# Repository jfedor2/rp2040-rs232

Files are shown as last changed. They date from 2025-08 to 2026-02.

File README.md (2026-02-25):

# RS-232 adapter with an RP2040 chip

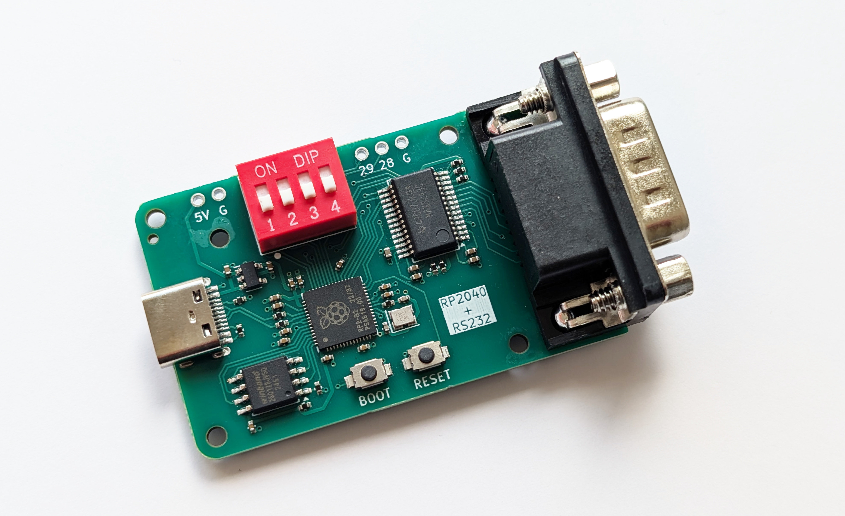
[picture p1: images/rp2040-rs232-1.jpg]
rp2040-rs232 board


This repository contains design files and firmware for a board that can be used as an RS-232 (serial) to USB adapter. It has an RP2040 chip for the application logic and a MAX3243 chip for the serial interface.

The provided firmware supports classic serial mice, two types of 3D mice (Magellan/SpaceMouse and Spaceball 2003), the SpaceOrb 360 game controller, and can also act as a generic serial-to-USB adapter.

## How to make the device

I used [JLCPCB](https://jlcpcb.com/) to make the board. The files in the [fabrication](fabrication) folder can be used with JLCPCB directly. If you want to use some other service, check the file formats that they expect. When ordering from JLCPCB, upload the Gerber zip, leave all the settings at default (you can choose the PCB color), then enable "PCB Assembly" and upload the BOM and CPL files in the next step.

Models for a 3D-printable case can be found in the [3d-printed-case](3d-printed-case) folder. The cases uses four M2x12 countersunk screws and (optionally) one M2x4 screw to secure the board to the case.

## Firmware

The provided firmware combines five separate projects and lets you choose between them using the DIP switches on the board. This way you can have a multi-purpose adapter without having to re-flash the firmware every time.

To flash the board with the firmware, press and hold the BOOT button, then while holding it press and release the RESET button. A drive named "RPI-RP2" should appear on your computer. Copy the [multi-firmware.uf2](https://github.com/jfedor2/rp2040-rs232/releases/latest/download/multi-firmware.uf2) file to that drive. After it's done flashing the drive will disappear and that's it.

project | description | DIP switch setting
------- | ----------- | ------------------
[HID Remapper](https://github.com/jfedor2/hid-remapper) | Adapts classic serial mice to USB | off-off-off-ON
[spaceball-2003](https://github.com/jfedor2/spaceball-2003) | Lets you use a Spaceball 2003 with modern software | off-off-ON-off
[magellan-spacemouse](https://github.com/jfedor2/magellan-spacemouse) | Lets you use a serial Magellan/SpaceMouse with modern software | off-off-ON-ON
[pico-uart-bridge](https://github.com/Noltari/pico-uart-bridge) | Generic USB-to-serial bridge | off-ON-off-off
[spaceorb360](https://github.com/jfedor2/spaceorb360)<br>(spacemouse) | Lets you use a SpaceOrb 360 with modern CAD software | off-ON-off-ON
[spaceorb360](https://github.com/jfedor2/spaceorb360)<br>(joystick) | Lets you use a SpaceOrb 360 with games like Descent | off-ON-ON-off

You can of course use any other firmware meant for the RP2040 chip if you want.

## How to compile

The easiest way to compile the firmware is to let GitHub do it for you. This repository has GitHub Actions that build the firmware, so you can just fork, enable Actions, make your changes, wait for the job to complete, and look for the binary in the artifacts produced.

To compile the firmware on your machine, use the following steps (details may vary depending on your Linux distribution):

```
sudo apt install gcc-arm-none-eabi libnewlib-arm-none-eabi libstdc++-arm-none-eabi-newlib
git clone https://github.com/jfedor2/rp2040-rs232.git
cd rp2040-rs232/multi-firmware
git submodule update --init
for submodule in hid-remapper magellan-spacemouse spaceball-2003 pico-uart-bridge spaceorb360
do
cd $submodule; git submodule update --init; cd ..
done
mkdir build
cd build
cmake ..
make
```

## License

The software in this repository is licensed under the [MIT License](LICENSE), unless stated otherwise. 

The hardware designs in this repository are licensed under the Creative Commons Attribution 4.0 International license ([CC BY 4.0](https://creativecommons.org/licenses/by/4.0/)), unless stated otherwise.

## Acknowledgments

PCB design uses [Type-C.pretty](https://github.com/ai03-2725/Type-C.pretty) library by [ai03-2725](https://github.com/ai03-2725).

Multi-firmware includes [pico-uart-bridge](https://github.com/Noltari/pico-uart-bridge) by [Noltari](https://github.com/Noltari).

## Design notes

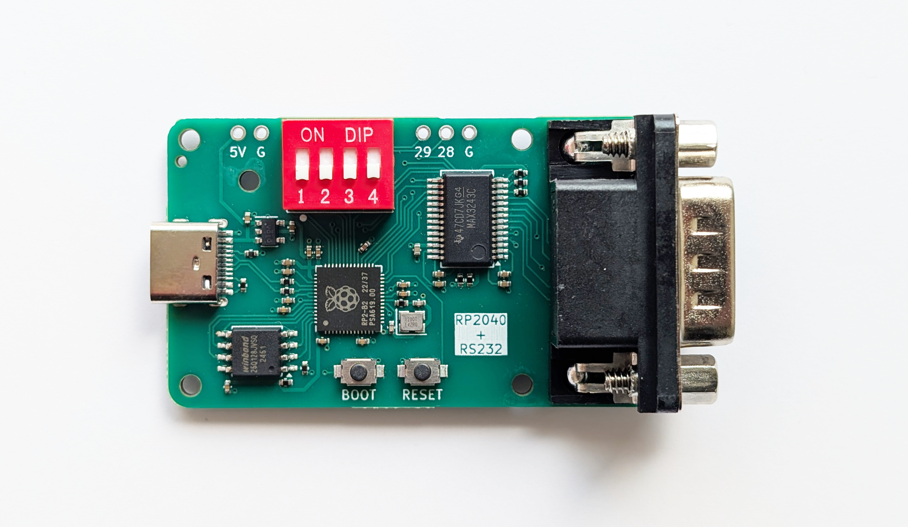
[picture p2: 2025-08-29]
images/rp2040-rs232-2.jpg

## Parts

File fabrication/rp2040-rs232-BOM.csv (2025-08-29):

Value | Reference | Footprint | LCSC
100n | C1,C2,C3,C4,C5,C6,C7,C8,C9,C16 | Capacitor_SMD:C_0402_1005Metric | C1525
1u | C10,C11,C12,C13,C17,C18,C19,C20 | Capacitor_SMD:C_0402_1005Metric | C52923
15p | C14,C15 | Capacitor_SMD:C_0402_1005Metric | C1548
10u | C21 | Capacitor_SMD:C_0402_1005Metric | C15525
DE9_Pins | J1 | DE-9:C19077344 | C19077344
27 | R1,R2 | Resistor_SMD:R_0402_1005Metric | C138021
10k | R3,R4,R6,R10,R11,R12 | Resistor_SMD:R_0402_1005Metric | C25744
1k | R5,R7 | Resistor_SMD:R_0402_1005Metric | C11702
5.1k | R8,R9 | Resistor_SMD:R_0402_1005Metric | C25905
SW_DIP_x04 | SW1 | DIP:C92645 | C92645
SW_Push | SW19,SW20 | SW:C720477 | C720477
RP2040 | U1 | RP2040:RP2040-QFN-56 | C2040
TLV73333PDBV | U2 | SOT-23-5:SOT-23-5 | C134139
W25Q128JVS | U3 | SOIC:SOIC-8_5.23x5.23mm_P1.27mm | C97521
MAX3243 | U5 | MAX3243:SSOP-28_5.3x10.2mm_P0.65mm | C414614
HRO-TYPE-C-31-M-12 | USB1 | Type-C:HRO-TYPE-C-31-M-12-Assembly | C165948
Crystal_GND24 | Y1 | Crystal:Crystal_SMD_2520-4Pin_2.5x2.0mm | C90603

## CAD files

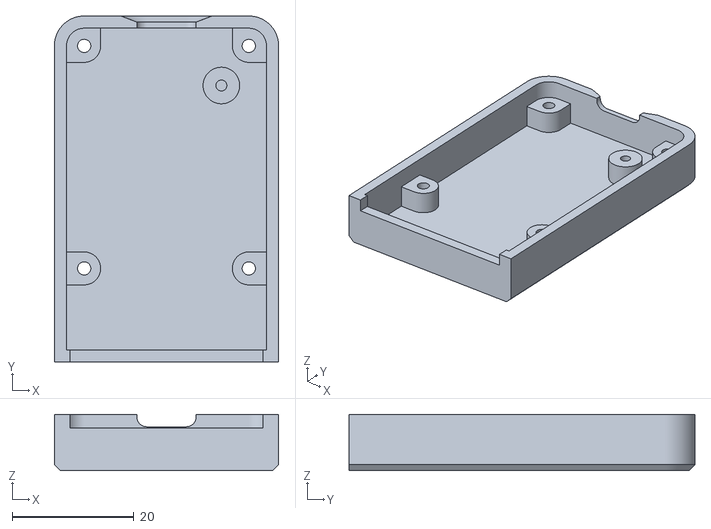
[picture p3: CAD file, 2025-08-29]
3d-printed-case/rp2040-rs232-Bottom.stl
36.8 x 56.8 x 9.23

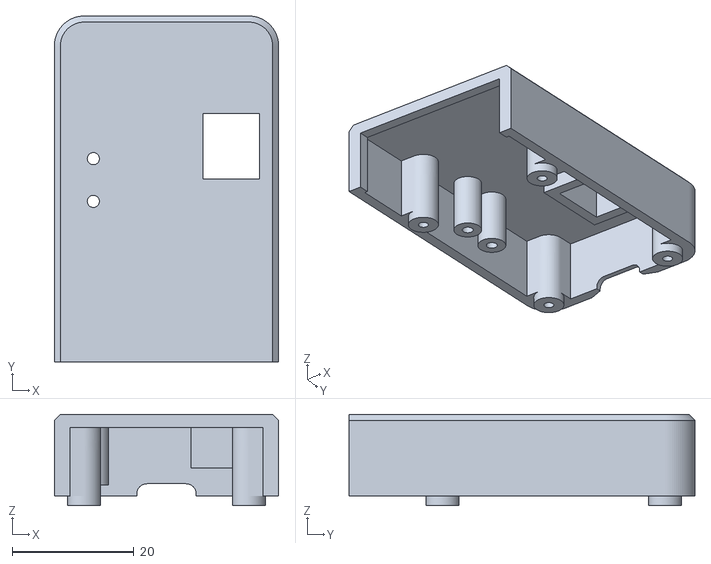
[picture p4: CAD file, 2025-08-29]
3d-printed-case/rp2040-rs232-Top.stl
36.8 x 56.8 x 15.0

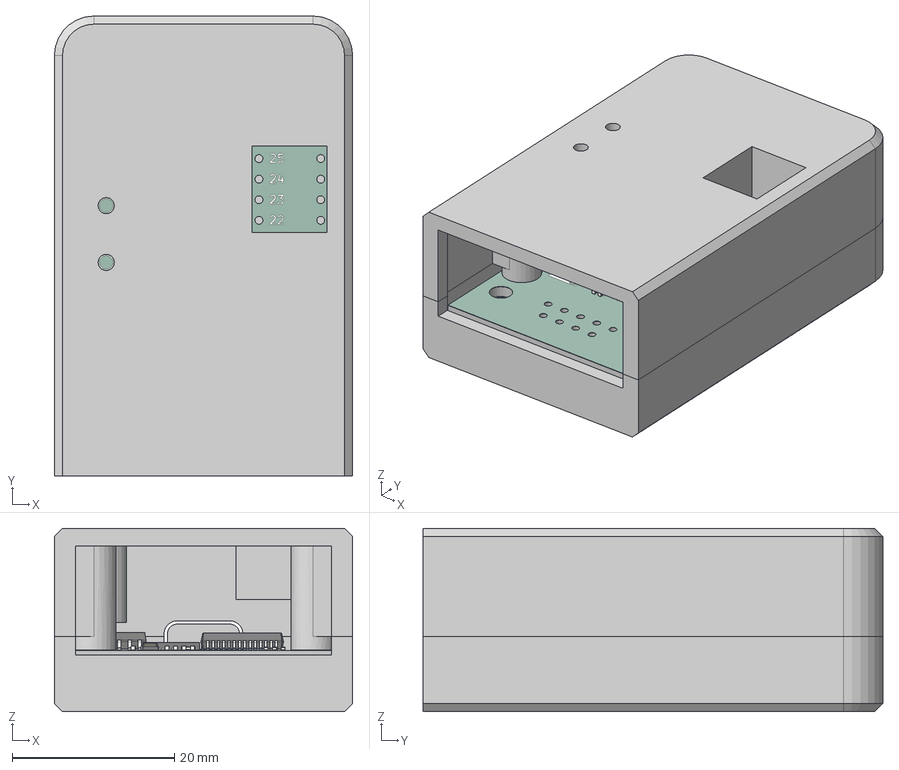
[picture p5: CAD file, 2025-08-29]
3d-printed-case/rp2040-rs232-case.step
36.8 x 56.8 x 22.6 mm
R_0402_1005Metric x 12
HRO-TYPE-C-31-M-12
C_0402_1005Metric x 21
SSOP-28_5.3x10.2mm_P0.65mm
Crystal_SMD_2520-4Pin_2.5x2.0mm
SOIC-8_5.3x5.3mm_P1.27mm
QFN-56-1EP_7x7mm_P0.4mm_EP5.6x5.6mm
SOT-23-5
rp2040-rs232_silkscreen
rp2040-rs232_soldermask
rp2040-rs232_PCB

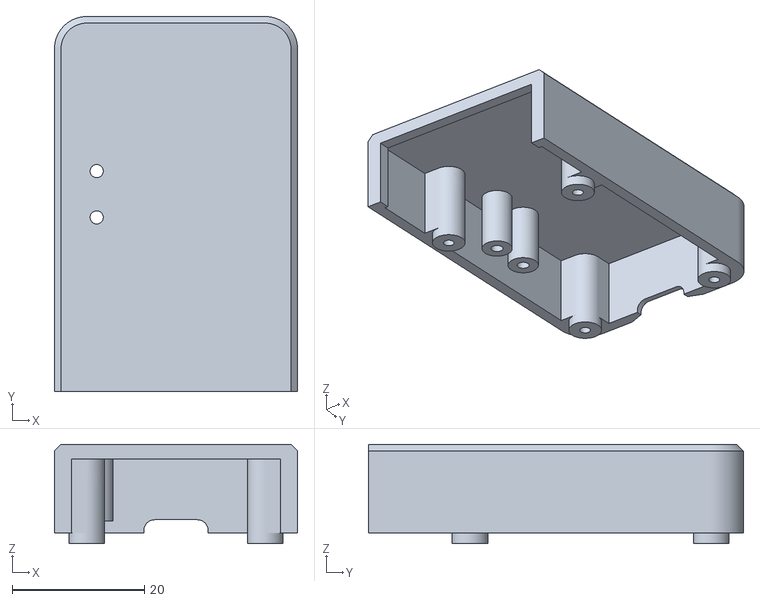
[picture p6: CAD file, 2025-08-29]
3d-printed-case/rp2040-rs232-Top-no-dip-switch-window.stl
36.8 x 56.8 x 15.0

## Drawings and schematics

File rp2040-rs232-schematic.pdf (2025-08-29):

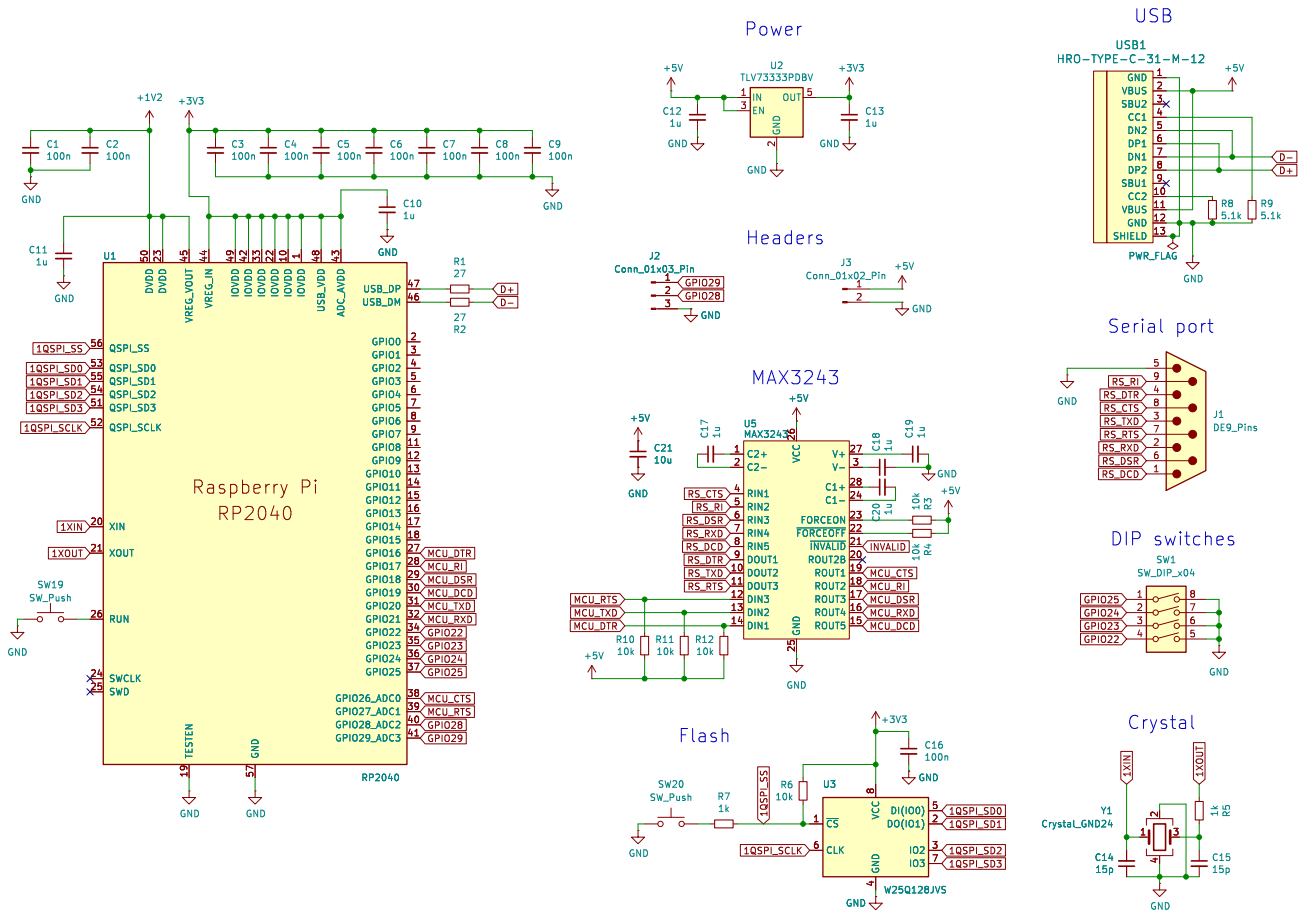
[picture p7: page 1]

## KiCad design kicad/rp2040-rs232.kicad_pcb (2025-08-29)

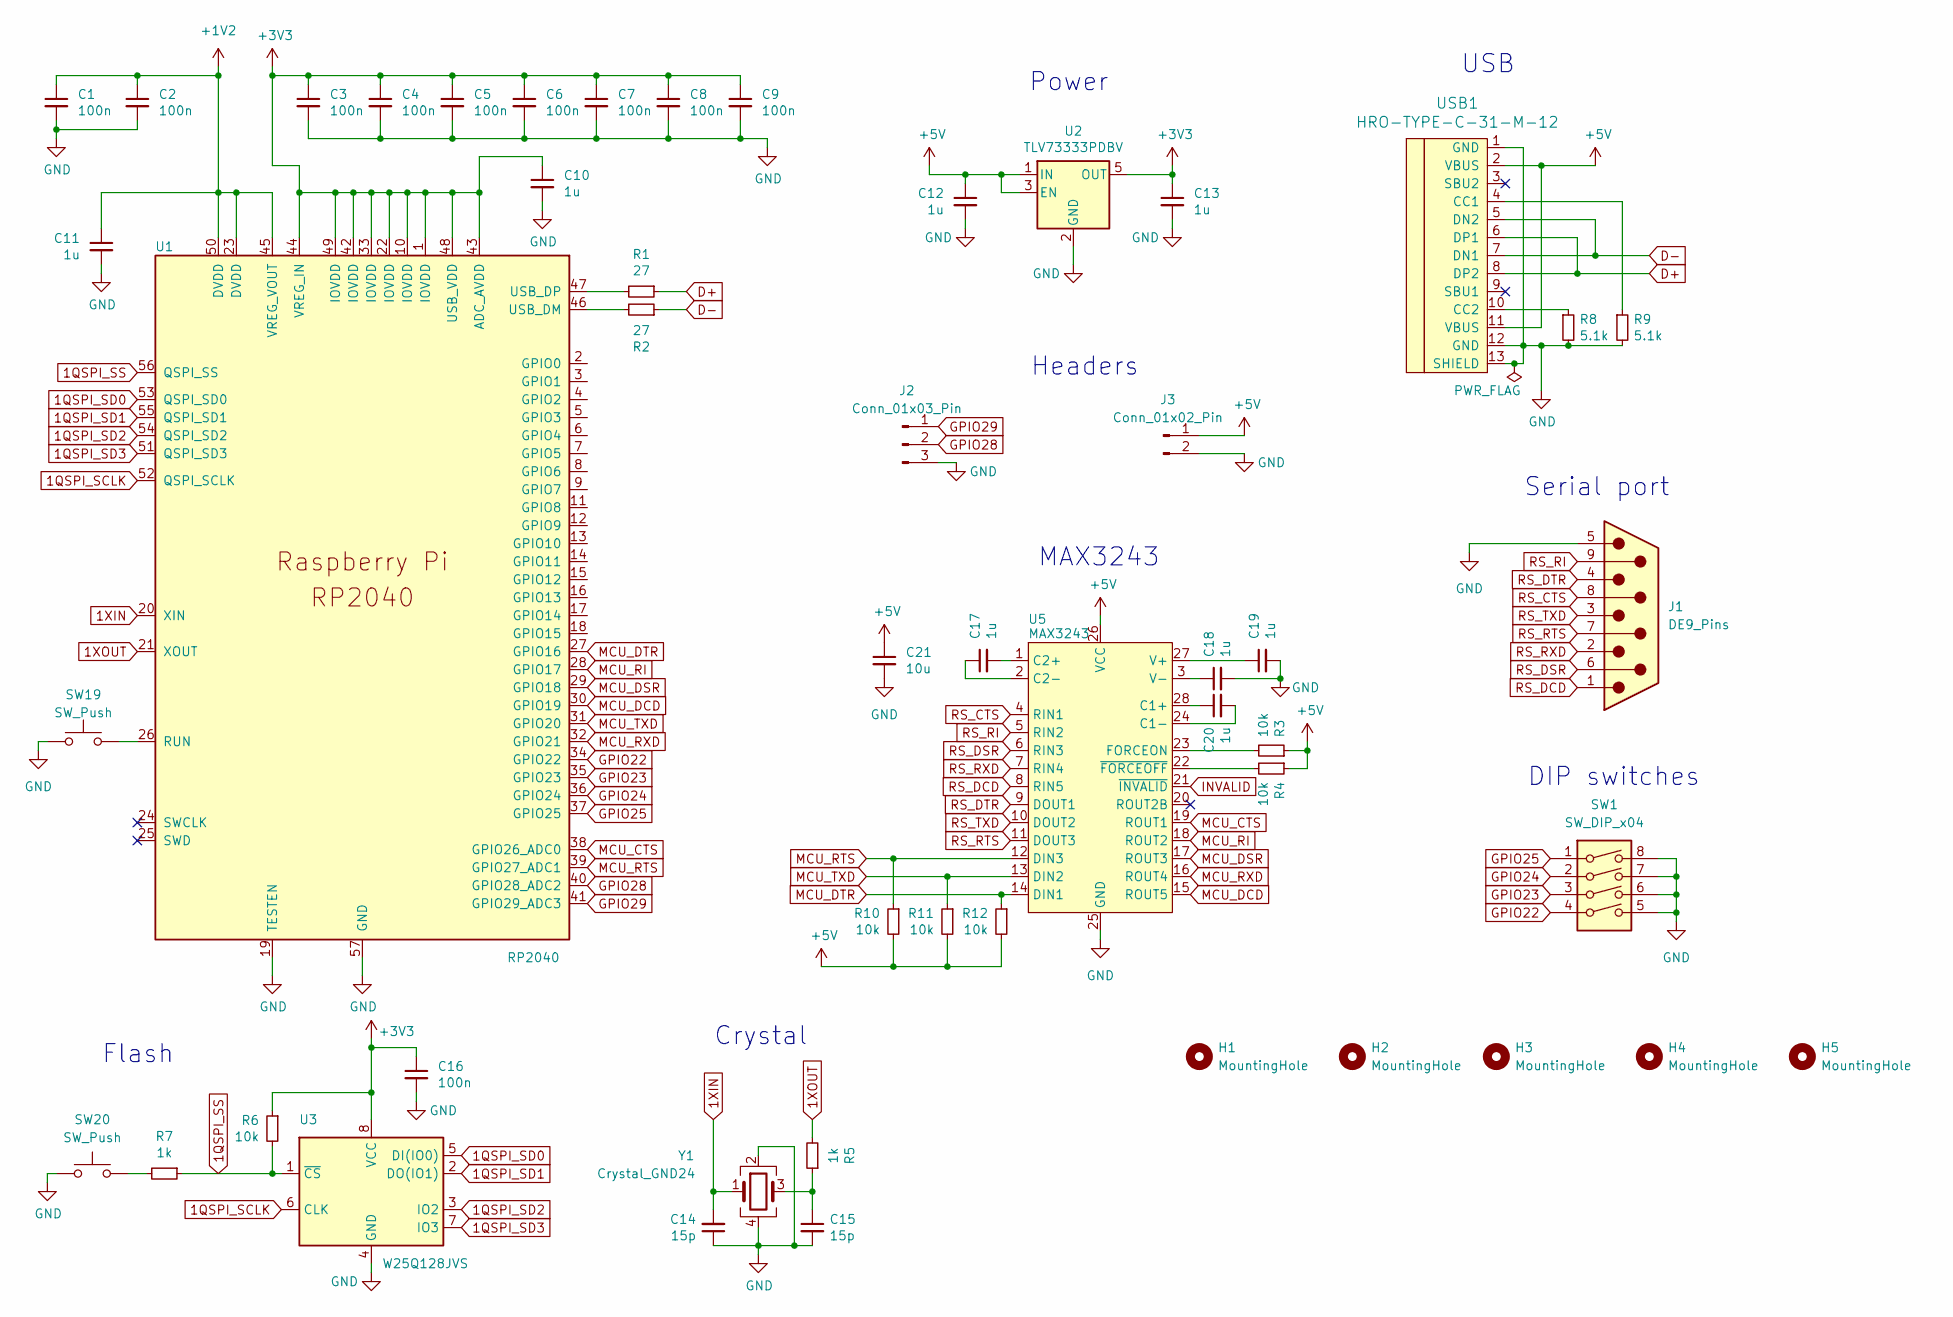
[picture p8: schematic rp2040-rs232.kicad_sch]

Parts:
C1, C2, C3, C4, C5, C6, C7, C8, C9, C16: 100n; C_0402_1005Metric; LCSC C1525
C10, C11, C12, C13, C17, C18, C19, C20: 1u; C_0402_1005Metric; LCSC C52923
C14, C15: 15p; C_0402_1005Metric; LCSC C1548
C21: 10u; C_0402_1005Metric; LCSC C15525
H1, H2, H3, H4, H5: MountingHole; MountingHole_2.2mm_M2
J1: DE9_Pins; C19077344; LCSC C19077344
J2: Conn_01x03_Pin; PinHeader_1x03_P2.54mm_Vertical
J3: Conn_01x02_Pin; PinHeader_1x02_P2.54mm_Vertical
R1, R2: 27; R_0402_1005Metric; LCSC C138021
R3, R4, R6, R10, R11, R12: 10k; R_0402_1005Metric; LCSC C25744
R5, R7: 1k; R_0402_1005Metric; LCSC C11702
R8, R9: 5.1k; R_0402_1005Metric; LCSC C25905
SW1: SW_DIP_x04; C92645; LCSC C92645
SW19, SW20: SW_Push; C720477; LCSC C720477
U1: RP2040; RP2040-QFN-56; LCSC C2040
U2: TLV73333PDBV; SOT-23-5; LCSC C134139
U3: W25Q128JVS; SOIC-8_5.23x5.23mm_P1.27mm; LCSC C97521
U5: MAX3243; SSOP-28_5.3x10.2mm_P0.65mm; LCSC C414614
USB1: HRO-TYPE-C-31-M-12; HRO-TYPE-C-31-M-12-Assembly; LCSC C165948
Y1: Crystal_GND24; Crystal_SMD_2520-4Pin_2.5x2.0mm; LCSC C90603

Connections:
1QSPI_SCLK: U1.52 (QSPI_SCLK), U3.6 (CLK)
1QSPI_SD0: U1.53 (QSPI_SD0), U3.5 (DI(IO0))
1QSPI_SD1: U1.55 (QSPI_SD1), U3.2 (DO(IO1))
1QSPI_SD2: U1.54 (QSPI_SD2), U3.3 (IO2)
1QSPI_SD3: U1.51 (QSPI_SD3), U3.7 (IO3)
1QSPI_SS: R6.2, R7.1, U1.56 (QSPI_SS), U3.1 (~CS)
1XIN: C14.2, U1.20 (XIN), Y1.1
1XOUT: R5.2, U1.21 (XOUT)
+1V2: C1.1, C2.1, C11.1, U1.23 (DVDD), U1.45 (VREG_VOUT), U1.50 (DVDD)
+3V3: C3.1, C4.1, C5.1, C6.1, C7.1, C8.1, C9.1, C10.1, C13.1, C16.1, R6.1, U1.1 (IOVDD), U1.10 (IOVDD), U1.22 (IOVDD), U1.33 (IOVDD), U1.42 (IOVDD), U1.43 (ADC_AVDD), U1.44 (VREG_IN), U1.48 (USB_VDD), U1.49 (IOVDD), U2.5 (OUT), U3.8 (VCC)
+5V: C12.1, C21.1, J3.1, R3.1, R4.1, R10.2, R11.2, R12.2, U2.1 (IN), U2.3 (EN), U5.26 (VCC), USB1.2 (VBUS), USB1.11 (VBUS)
D+: R1.1, USB1.6 (DP1), USB1.8 (DP2)
D-: R2.1, USB1.5 (DN2), USB1.7 (DN1)
GND: C1.2, C2.2, C3.2, C4.2, C5.2, C6.2, C7.2, C8.2, C9.2, C10.2, C11.2, C12.2, C13.2, C14.1, C15.2, C16.2, C18.2, C19.2, C21.2, J1.5, J2.3, J3.2, R8.2, R9.2, SW1.5, SW1.6, SW1.7, SW1.8, SW19.1, SW20.1, U1.19 (TESTEN), U1.57 (GND), U2.2 (GND), U3.4 (GND), U5.25 (GND), USB1.1 (GND), USB1.12 (GND), USB1.13 (SHIELD), Y1.2, Y1.4
GPIO22: SW1.4, U1.34 (GPIO22)
GPIO23: SW1.3, U1.35 (GPIO23)
GPIO24: SW1.2, U1.36 (GPIO24)
GPIO25: SW1.1, U1.37 (GPIO25)
GPIO28: J2.2, U1.40 (GPIO28_ADC2)
GPIO29: J2.1, U1.41 (GPIO29_ADC3)
INVALID: U5.21 (~INVALID)
MCU_CTS: U1.38 (GPIO26_ADC0), U5.19 (ROUT1)
MCU_DCD: U1.30 (GPIO19), U5.15 (ROUT5)
MCU_DSR: U1.29 (GPIO18), U5.17 (ROUT3)
MCU_DTR: R12.1, U1.27 (GPIO16), U5.14 (DIN1)
MCU_RI: U1.28 (GPIO17), U5.18 (ROUT2)
MCU_RTS: R10.1, U1.39 (GPIO27_ADC1), U5.12 (DIN3)
MCU_RXD: U1.32 (GPIO21), U5.16 (ROUT4)
MCU_TXD: R11.1, U1.31 (GPIO20), U5.13 (DIN2)
unnamed: C15.1, R5.1, Y1.3
unnamed: R7.2, SW20.2
unnamed: SW19.2, U1.26 (RUN)
unnamed: R2.2, U1.46 (USB_DM)
unnamed: R1.2, U1.47 (USB_DP)
unnamed: C20.1, U5.28 (C1+)
unnamed: C20.2, U5.24 (C1-)
unnamed: C17.2, U5.1 (C2+)
unnamed: C17.1, U5.2 (C2-)
unnamed: R3.2, U5.23 (FORCEON)
unnamed: C19.1, U5.27 (V+)
unnamed: C18.1, U5.3 (V-)
unnamed: R4.2, U5.22 (~FORCEOFF)
unnamed: R9.1, USB1.4 (CC1)
unnamed: R8.1, USB1.10 (CC2)
RS_CTS: J1.8, U5.4 (RIN1)
RS_DCD: J1.1, U5.8 (RIN5)
RS_DSR: J1.6, U5.6 (RIN3)
RS_DTR: J1.4, U5.9 (DOUT1)
RS_RI: J1.9, U5.5 (RIN2)
RS_RTS: J1.7, U5.11 (DOUT3)
RS_RXD: J1.2, U5.7 (RIN4)
RS_TXD: J1.3, U5.10 (DOUT2)

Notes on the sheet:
Crystal
Headers
MAX3243
Serial port
DIP switches
Power
Flash
USB

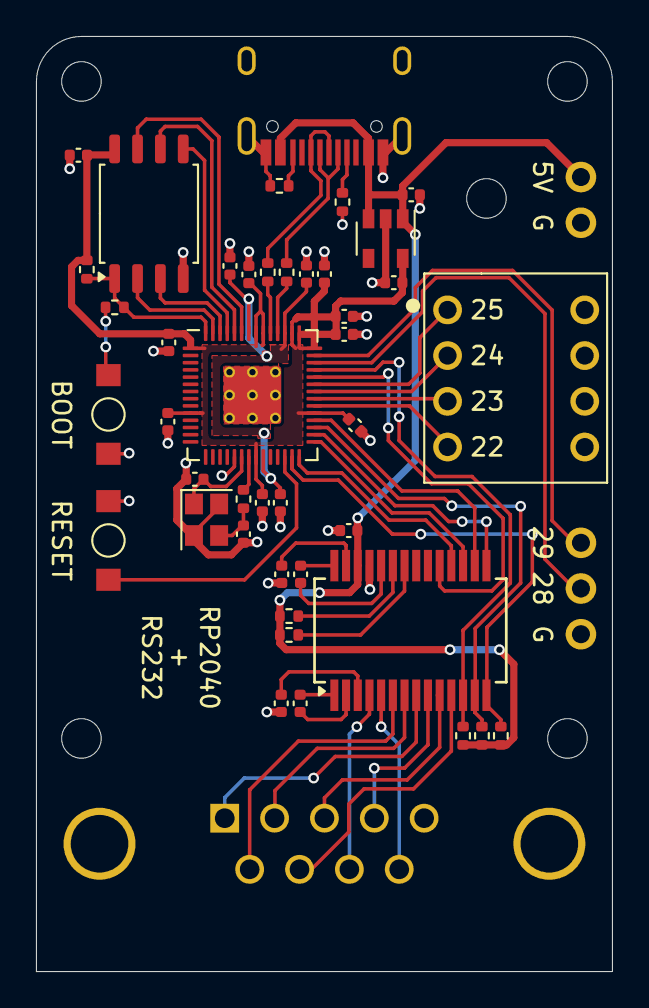
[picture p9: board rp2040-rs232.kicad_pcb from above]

Board: 2 copper layers, 32.0 x 52.0 mm, 50 parts (0 on the bottom side), 51 nets.

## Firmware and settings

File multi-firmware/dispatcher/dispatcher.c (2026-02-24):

#include "cmsis_gcc.h"
#include "hardware/gpio.h"
#include "hardware/structs/m0plus.h"
#include "pico/stdlib.h"

#define SELECT_PIN_MASK (1 << 22 | 1 << 23 | 1 << 24 | 1 << 25)

// DIP switch setting for each app.
#define APP1_PIN_STATE (0b0001 << 22)
#define APP2_PIN_STATE (0b0010 << 22)
#define APP3_PIN_STATE (0b0011 << 22)
#define APP4_PIN_STATE (0b0100 << 22)
#define APP5_PIN_STATE (0b0101 << 22)
#define APP6_PIN_STATE (0b0110 << 22)

typedef void (*app_entry_t)(void);

void jump_to_app(uint32_t app_address) {
    // The first word at the app's address is the initial stack pointer.
    // The second word is the address of the reset handler (the entry point).
    uint32_t* app_vectors = (uint32_t*) app_address;
    uint32_t app_sp = app_vectors[0];
    app_entry_t app_entry = (app_entry_t) app_vectors[1];

    __disable_irq();

    // Set the Vector Table Offset Register (VTOR) to the app's vector table.
    ppb_hw->vtor = app_address;

    // Set the main stack pointer (MSP) to the app's stack pointer.
    __set_MSP(app_sp);

    __enable_irq();

    // Jump to the application's entry point.
    app_entry();

    // Never reached.
    while (1) {
        tight_loop_contents();
    }
}

int main() {
    gpio_init_mask(SELECT_PIN_MASK);
    gpio_set_dir_in_masked(SELECT_PIN_MASK);
    for (uint8_t i = 0; i < 32; i++) {
        if ((SELECT_PIN_MASK >> i) & 1) {
            gpio_pull_up(i);
        }
    }

    // Wait for the pull-ups to stabilize.
    sleep_ms(10);

    uint32_t target_app_address;

    uint32_t pin_state = (~gpio_get_all()) & SELECT_PIN_MASK;

    if (pin_state == APP1_PIN_STATE) {
        target_app_address = APP1_START_ADDRESS;
    } else if (pin_state == APP2_PIN_STATE) {
        target_app_address = APP2_START_ADDRESS;
    } else if (pin_state == APP3_PIN_STATE) {
        target_app_address = APP3_START_ADDRESS;
    } else if (pin_state == APP4_PIN_STATE) {
        target_app_address = APP4_START_ADDRESS;
    } else if (pin_state == APP5_PIN_STATE) {
        target_app_address = APP5_START_ADDRESS;
    } else if (pin_state == APP6_PIN_STATE) {
        target_app_address = APP6_START_ADDRESS;
    } else {
        target_app_address = APP1_START_ADDRESS;
    }

    for (uint8_t i = 0; i < 32; i++) {
        if ((SELECT_PIN_MASK >> i) & 1) {
            gpio_disable_pulls(i);
            gpio_deinit(i);
        }
    }

    jump_to_app(target_app_address);

    return 0;  // Never reached.
}
